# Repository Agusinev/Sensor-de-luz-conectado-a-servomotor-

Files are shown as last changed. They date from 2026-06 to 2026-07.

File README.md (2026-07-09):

# Sensor-de-luz-conectado-a-servomotor-
Nuestro sistema busca poder utilizar sensores de luz para permitir que el servomotor gire en direccion donde hay mas luz, esto luego puediendo ser aplicado a por ejemplo, sistemas que requieran luz directa.
## Equipo
| Integrante | Rol | GitHub |

| - - - - - - - - - - - - -| - - - - - - - - - - - - - - - - - - -| - - - - - - - - - - - -|

| --Agustin Bratti --- | ---------Diseño 3D----------| --- @Agusinev --- |

| -Franco Lombardi- | ------Software / Firmware------|@francolombardi-123 | 

## Descripcion del Problema
El principal problema es la ineficiencia hasta cierto punto, dado que la recoleccion de luz solar no es suficiente estando inmovil, por ende, buscando una solucion que permita al sistema rotar entorno a mirar a una fuente de luz, en este caso el sol
## Arquitectura del Sistema (EJEMPLO CAMBIAR)
Sensor pwr led 4 pin fotosensible -> ESP32 -> Firebase -> Dashboard Node - RED -> Servomotor gs360
## Instrucciones de Uso 
Mediante sensores de luz, subir codigo a arduino, al detectar mayores niveles de luz el servomotor girara.
### Cargar el firmware
1. Desconectar todos los cables entre Arduino y NodeMCU
2. Conectar el **Arduino Uno** al PC y cargar `arduino_seguidor.ino`
3. Conectar el **NodeMCU** al PC y cargar `nodemcu_seguidor.ino`
4. Reconectar todos los cables
## Estructura del Repositorio
- ‘ firmware / ‘ -- Codigo fuente Arduino
- ‘ hardware / ‘ -- Esquematicos y BOM
- ‘ diseno -3 d / ‘ -- Archivos Fusion 360 y planos
- ‘ testing / ‘ -- Protocolos y evidencias
- ‘ docs / ‘ -- Reporte final

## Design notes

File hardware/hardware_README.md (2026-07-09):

# Hardware

Esta carpeta contiene el esquemático de conexiones y la lista de componentes del sistema.

## Lista de componentes (BOM)

| Componente | Modelo | Cantidad | Función |
|---|---|---|---|
| Microcontrolador principal | Arduino Uno | 1 | Lee los sensores LDR y calcula el ángulo |
| Módulo WiFi | NodeMCU ESP8266 | 1 | Mueve el servo y expone la API REST por WiFi |
| Servo motor | GS-3630BB | 1 | Rota la plataforma del destilador |
| Sensor de luz | Módulo LDR (4 pines) | 2 | Detectan la intensidad lumínica en ambos lados |
| Resistencia | 1 kΩ | 1 | Divisor de voltaje (R1) |
| Resistencia | 2 kΩ | 1 | Divisor de voltaje (R2) |
| Protoboard | — | 1 | Conexiones sin soldar |
| Cables dupont | Macho-Macho / Macho-Hembra | varios | Conexiones entre componentes |

## Esquema de conexiones

### Sensores LDR

| Pin módulo LDR | Conectar a |
|---|---|
| VCC | 3.3V NodeMCU |
| GND | GND común (protoboard) |
| A0 (LDR 1) | Pin A0 Arduino |
| A0 (LDR 2) | Pin A1 Arduino |
| D0 | No conectar |

### Servo GS-3630BB

| Cable | Conectar a |
|---|---|
| Rojo (VCC) | 5V Arduino |
| Café (GND) | GND común (protoboard) |
| Amarillo (señal) | Pin D1 NodeMCU |

### Divisor de voltaje (TX Arduino → NodeMCU)

El Arduino Uno opera a 5V lógicos y el NodeMCU a 3.3V. Se requiere un divisor de voltaje para proteger el NodeMCU.

```
TX Arduino (pin 1) → R1 (1kΩ) → punto medio → R2 (2kΩ) → GND
                                      │
                                  D7 NodeMCU
```

| Conexión | Desde | Hacia |
|---|---|---|
| R1 pata 1 | Pin TX (pin 1) Arduino | — |
| R1 pata 2 | — | Punto medio |
| R2 pata 1 | Punto medio | — |
| R2 pata 2 | — | GND común |
| Punto medio | — | Pin D7 NodeMCU |

### GND común

Todos los siguientes GND deben ir a la misma fila negativa de la protoboard, con un cable hacia el GND del Arduino:

- GND Arduino
- GND NodeMCU
- GND LDR 1
- GND LDR 2
- GND Servo (cable café)
- Pata 2 de R2

## Notas importantes

- El cable del divisor de voltaje (D7 NodeMCU) debe desconectarse antes de cargar código al NodeMCU para evitar interferencias
- El servo se alimenta desde el 5V del Arduino pero recibe la señal PWM desde el NodeMCU (3.3V), lo cual es compatible con el GS-3630BB
- Ambos microcontroladores se alimentan por USB independientes

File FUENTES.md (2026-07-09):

# Fuentes del Proyecto

## Librerías utilizadas

| Librería | Versión | Fuente |
|---|---|---|
| `Arduino.h` | Incluida en Arduino IDE | Arduino Core |
| `ESP8266WiFi.h` | Incluida en ESP8266 Core | esp8266 by ESP8266 Community |
| `ESP8266WebServer.h` | Incluida en ESP8266 Core | esp8266 by ESP8266 Community |
| `SoftwareSerial.h` | Incluida en ESP8266 Core | esp8266 by ESP8266 Community |
| `Servo.h` | Incluida en ESP8266 Core | esp8266 by ESP8266 Community |

## Datasheets y referencias de componentes

| Componente | Referencia |
|---|---|
| NodeMCU ESP8266 | https://www.espressif.com/sites/default/files/documentation/esp8266-technical_reference_en.pdf |
| Arduino Uno | https://docs.arduino.cc/hardware/uno-rev3 |
| Servo GS-3630BB | Datasheet del fabricante Guang Sheng Servo |
| Módulo LDR 4 pines | Referencia genérica de módulo fotoresistivo con comparador LM393 |

## Código externo adaptado

No se utilizó código externo copiado directamente. El firmware fue desarrollado específicamente para este proyecto.

## Uso de Inteligencia Artificial

Durante el desarrollo del proyecto se utilizó **Claude (Anthropic)** como herramienta de apoyo para el diseño del sistema, la resolución de problemas de hardware y la implementación del firmware.

### Desarrollo del firmware

- **Herramienta:** Claude by Anthropic (claude.ai)
- **Uso:** apoyo en el diseño de la arquitectura de comunicación Serial entre Arduino y NodeMCU, implementación de la API REST en el ESP8266, resolución de conflictos entre librerías (Servo y SoftwareSerial), y depuración de problemas de niveles de voltaje en la comunicación Serial.
- **Adaptación:** todas las propuestas generadas fueron revisadas, probadas físicamente y modificadas por el equipo para adaptarlas a los componentes disponibles. Se realizaron múltiples iteraciones hasta lograr el funcionamiento correcto del sistema completo.
- **Validación:** el funcionamiento del firmware fue comprobado mediante pruebas experimentales con los sensores LDR, el servo motor y la API REST, verificando que el sistema respondiera correctamente a cambios de luz antes de darlo por finalizado.
- **Comprensión:** ambos integrantes revisaron el código final, comprenden la función de sus principales módulos y son capaces de explicar su funcionamiento durante la presentación del proyecto.

### Diseño del divisor de voltaje

Se utilizó Claude para calcular los valores de resistencias necesarios para reducir los 5V lógicos del Arduino a los 3.3V tolerados por el NodeMCU, usando la fórmula del divisor de voltaje resistivo.

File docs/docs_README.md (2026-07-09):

# Documentación del Proyecto

Esta carpeta contiene los informes y documentación generada durante el desarrollo del destilador solar automático.

## Contenido

| Archivo | Descripción |
|---|---|
| `informe-final.pdf` | Informe completo del proyecto con introducción, desarrollo y conclusiones |
| `presentacion.pptx` | Presentación del proyecto para exposición |

## Descripción del sistema

El sistema consiste en un destilador solar con seguimiento automático de la luz. Utiliza dos sensores LDR para detectar la posición del sol y un servo motor para rotar la plataforma del destilador hacia la fuente de mayor intensidad lumínica.

### Arquitectura

```
LDR 1 (A0) ──┐
              ├── Arduino Uno ── Serial TX ── Divisor de voltaje ── NodeMCU ESP8266 ── API REST (WiFi)
LDR 2 (A1) ──┘        │
                    Servo GS-3630BB (D1 NodeMCU)
```

### Flujo de datos

1. Los sensores LDR leen la intensidad de luz en ambos lados de la plataforma
2. El Arduino Uno calcula la diferencia y determina el ángulo del servo
3. El dato es enviado por Serial al NodeMCU ESP8266
4. El NodeMCU mueve el servo y expone los datos en tiempo real mediante una API REST accesible por IP WiFi local

## Instrucciones para cargar el firmware

1. Abrir Arduino IDE
2. Instalar el paquete **esp8266 by ESP8266 Community** desde el Gestor de tarjetas
3. Seleccionar la placa correspondiente:
   - Para el Arduino: `Arduino Uno`
   - Para el NodeMCU: `NodeMCU 1.0 (ESP-12E Module)`
4. Configurar las credenciales WiFi en `nodemcu_seguidor.ino`
5. Cargar `arduino_seguidor.ino` en el Arduino Uno
6. Cargar `nodemcu_seguidor.ino` en el NodeMCU

## Uso de la API

Una vez encendido el sistema, el NodeMCU imprime su IP en el monitor serie (9600 baudios). Con esa IP se puede acceder al endpoint:

```
GET http://[IP]/estado
```

Respuesta de ejemplo:
```json
{
  "ldr1": 512,
  "ldr2": 480,
  "angulo": 94
}
```

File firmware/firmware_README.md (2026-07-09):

# Firmware

Esta carpeta contiene el código fuente para los dos microcontroladores del sistema.

## Archivos

| Archivo | Microcontrolador | Descripción |
|---|---|---|
| `arduino_seguidor.ino` | Arduino Uno | Lee sensores LDR, calcula el ángulo y envía datos por Serial |
| `nodemcu_seguidor.ino` | NodeMCU ESP8266 | Recibe datos por Serial, mueve el servo y expone la API REST |

## Requisitos

### Arduino IDE
- Versión 1.8.x o superior

### Librerías necesarias

| Librería | Placa | Cómo instalar |
|---|---|---|
| `Arduino.h` | Arduino Uno | Incluida por defecto |
| `ESP8266WiFi.h` | NodeMCU | Incluida con el paquete esp8266 |
| `ESP8266WebServer.h` | NodeMCU | Incluida con el paquete esp8266 |
| `SoftwareSerial.h` | NodeMCU | Incluida con el paquete esp8266 |
| `Servo.h` | NodeMCU | Incluida con el paquete esp8266 |

### Soporte para NodeMCU
Agregar esta URL en Archivo → Preferencias → Gestor de URLs adicionales:
```
http://arduino.esp8266.com/stable/package_esp8266com_index.json
```
Luego instalar **esp8266 by ESP8266 Community** desde el Gestor de tarjetas.

## Configuración antes de cargar

En `nodemcu_seguidor.ino`, modificar las siguientes líneas con las credenciales de la red WiFi:

```cpp
const char* SSID     = "TU_RED_WIFI";
const char* PASSWORD = "TU_CONTRASENA";
```

## Orden de carga

1. Desconectar todos los cables entre Arduino y NodeMCU
2. Conectar el **Arduino Uno** al PC y cargar `arduino_seguidor.ino`
3. Conectar el **NodeMCU** al PC y cargar `nodemcu_seguidor.ino`
4. Reconectar todos los cables

> ⚠️ El cable del divisor de voltaje (TX Arduino → D7 NodeMCU) puede interferir con la carga del código. Desconectarlo antes de cargar y reconectarlo después.

## Lógica del firmware

### arduino_seguidor.ino

- Lee los valores analógicos de LDR1 (A0) y LDR2 (A1)
- Calcula la diferencia entre ambos sensores
- Si la diferencia supera el umbral de 30, incrementa o decrementa el ángulo en 2 grados
- Envía los valores de LDR1, LDR2 y ángulo al NodeMCU cada 500ms por Serial

### nodemcu_seguidor.ino

- Recibe los datos del Arduino por SoftwareSerial (pin D7)
- Mueve el servo GS-3630BB al ángulo recibido (pin D1)
- Expone el endpoint `GET /estado` con los datos en formato JSON
- Imprime la IP asignada por el router en el monitor serie al iniciar

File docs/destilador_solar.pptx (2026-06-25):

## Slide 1

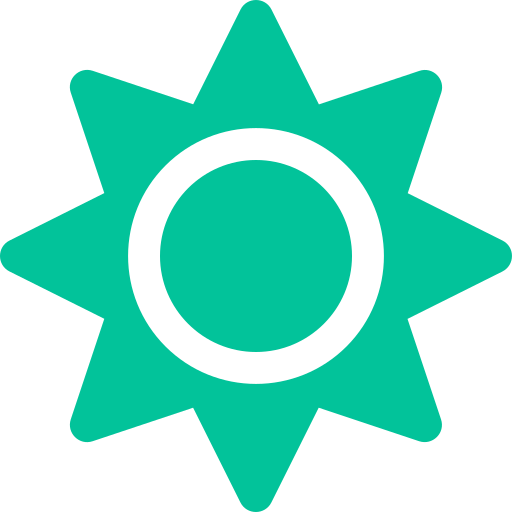
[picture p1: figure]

Destilador Solar

Automático

Solución tecnológica para la escasez de agua potable en Arica

Franco Lombardi · Agustín Bratti

2025

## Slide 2

El Problema: Escasez de Agua en Arica

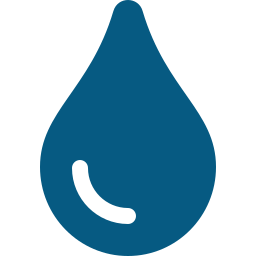
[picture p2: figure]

< 1mm

lluvia anual promedio

Arica es uno de los lugares más áridos del mundo, con precipitaciones casi nulas.

60%

déficit hídrico

La región enfrenta un déficit crítico de agua potable que afecta a miles de familias.

340

días de sol al año

Alta radiación solar disponible como recurso energético gratuito y renovable.

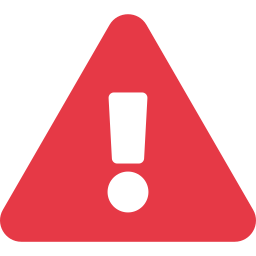
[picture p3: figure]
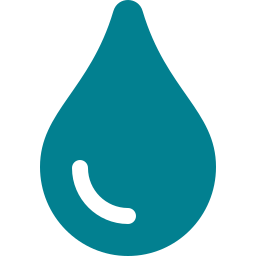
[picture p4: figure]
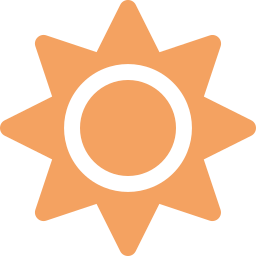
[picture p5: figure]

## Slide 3

Nuestra Solución

Destilador Solar con Seguimiento Automático

Un destilador solar convierte agua salada o contaminada en agua potable usando la energía del sol. Nuestro sistema incorpora sensores LDR y un servo motor para seguir automáticamente la trayectoria solar, maximizando la eficiencia de destilación durante todo el día.

1

Captación

Agua de mar o contaminada ingresa al sistema

2

Evaporación

El sol calienta el agua bajo el panel de vidrio

3

Condensación

El vapor se condensa en agua destilada pura

4

Recolección

Agua potable limpia lista para consumir

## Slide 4

Componentes del Sistema de Control

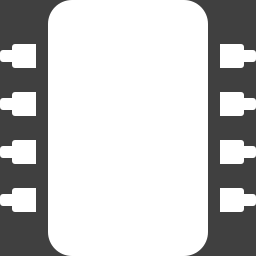
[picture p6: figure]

NodeMCU ESP8266

Cerebro del sistema. Procesa datos de sensores y controla el movimiento. Conectividad WiFi integrada para monitoreo remoto.

Servo GS-3630BB

Motor de alta precisión que rota la plataforma del destilador para seguir la posición óptima del sol durante el día.

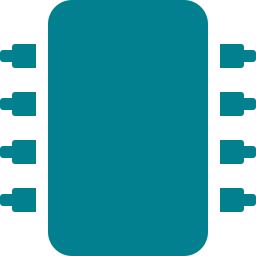
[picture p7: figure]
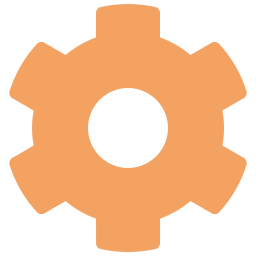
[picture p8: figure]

Sensores LDR x2

Detectan la intensidad de luz en ambos lados. La diferencia entre ellos indica hacia dónde debe girar el sistema.

API REST por WiFi

El NodeMCU expone una API HTTP accesible por IP local, permitiendo monitorear LDR1, LDR2 y ángulo en tiempo real.

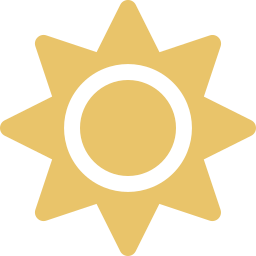
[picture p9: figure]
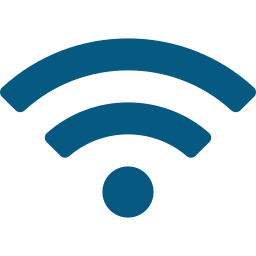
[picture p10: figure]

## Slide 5

Resultados del Proyecto

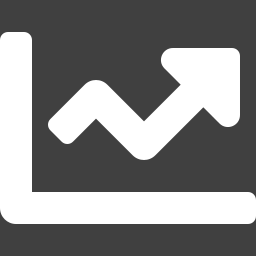
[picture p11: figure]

+35%

más eficiencia

vs. destilador fijo

180°

rango de rotación

seguimiento preciso

Real-time

monitoreo API

via WiFi por IP local

Logros del sistema:

Seguimiento solar automático funcional con dos sensores LDR y servo motor

Comunicación Serial estable entre Arduino Uno y NodeMCU ESP8266

API REST accesible por IP WiFi local con datos en tiempo real (LDR1, LDR2, ángulo)

Sistema autónomo que no requiere intervención manual durante operación

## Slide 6

Conclusiones

Viabilidad técnica comprobada

El sistema de seguimiento solar automático funciona correctamente, integrando hardware y software de forma eficiente.

Impacto social real

La solución aborda directamente el problema de escasez hídrica en Arica, aprovechando el recurso solar abundante de la región.

Escalabilidad

El diseño modular permite ampliar el sistema a múltiples unidades conectadas en red para mayor producción de agua.

Tecnología accesible

Componentes de bajo costo (Arduino, NodeMCU, sensores LDR) hacen la solución replicable en comunidades con recursos limitados.

Franco Lombardi · Agustín Bratti · 2025

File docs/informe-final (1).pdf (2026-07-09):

Universidad Adolfo Ibáñez
Ramo: TEI201

# Destilador Solar Automático

### Sistema de seguimiento solar con sensores LDR, servo motor y API REST por WiFi

Franco Lombardi
Agustín Bratti

Profesor
Sebastián Duarte

2026

## 1. Introducción

La escasez de agua potable es uno de los problemas más críticos que enfrenta la región de Arica. Con precipitaciones anuales inferiores a 1 mm y un déficit hídrico que afecta a una parte significativa de la población, la región requiere soluciones innovadoras que aprovechen los recursos naturales disponibles. Arica cuenta con aproximadamente 340 días de sol al año, lo que la convierte en un lugar ideal para implementar tecnologías solares.

El presente proyecto propone el diseño e implementación de un destilador solar automático capaz de convertir agua salada o contaminada en agua potable, aprovechando la energía solar de forma eficiente mediante un sistema de seguimiento automático de la posición del sol. El sistema integra sensores de luz, un servo motor y conectividad WiFi para el monitoreo remoto en tiempo real.

### 1.1 Objetivos

Objetivo general: Diseñar e implementar un destilador solar con seguimiento automático de la fuente de luz para maximizar la eficiencia de destilación.

Objetivos específicos:

- Implementar un sistema de lectura de sensores LDR para detectar la posición del sol.
- Controlar un servo motor que oriente la plataforma del destilador hacia la mayor fuente de luz.
- Establecer comunicación Serial entre un Arduino Uno y un NodeMCU ESP8266. •

Exponer los datos del sistema en tiempo real mediante una API REST accesible por WiFi.

## 2. Marco Teórico

### 2.1 Destilación solar

La destilación solar es un proceso que utiliza la energía del sol para evaporar agua y condensarla posteriormente, obteniendo agua purificada libre de sales, bacterias y contaminantes. El proceso consiste en cuatro etapas principales: captación del agua cruda, evaporación por efecto solar, condensación del vapor en una superficie fría y recolección del agua destilada.

La eficiencia de un destilador solar depende directamente de la cantidad de radiación solar que recibe la superficie de evaporación. Un destilador fijo presenta pérdidas significativas durante las horas de la mañana y la tarde, cuando el sol no está perpendicular a la superficie. El seguimiento automático de la posición solar permite incrementar la eficiencia hasta en un 35% respecto a un sistema fijo.

### 2.2 Sensores LDR

Un LDR (Light Dependent Resistor) es un componente electrónico cuya resistencia varía en función de la intensidad de luz que recibe. A mayor luminosidad, menor es su resistencia. Los módulos LDR de 4 pines utilizados en este proyecto incorporan un comparador LM393 que entrega tanto una salida analógica (A0) proporcional a la intensidad de luz como una salida digital (D0) para umbrales configurables.

### 2.3 Comunicación Serial entre microcontroladores

La comunicación UART (Universal Asynchronous Receiver-Transmitter) permite el intercambio de datos entre dispositivos mediante dos líneas: TX (transmisión) y RX (recepción). Un aspecto crítico al conectar un Arduino Uno (5V lógicos) con un NodeMCU ESP8266 (3.3V lógicos) es la diferencia de niveles de voltaje. Conectar directamente el TX del Arduino al RX del NodeMCU podría dañar el ESP8266, por lo que se requiere un divisor de voltaje resistivo.

### 2.4 API REST

Una API REST (Representational State Transfer) es una interfaz de comunicación que utiliza el protocolo HTTP para intercambiar datos. El NodeMCU ESP8266 actúa como servidor web, escuchando peticiones HTTP en la red WiFi local y respondiendo con datos en formato JSON. Esto permite monitorear el sistema desde cualquier dispositivo conectado a la misma red.

## 3. Hardware

### 3.1 Lista de componentes

Componente | Modelo | Cant. | Función
Microcontrolador | Arduino Uno | 1 | Lee sensores LDR y calcula ángulo
Módulo WiFi | NodeMCU ESP8266 | 1 | Mueve servo y expone API REST
Servo motor | GS-3630BB | 1 | Rota la plataforma del destilador
Sensor de luz | Módulo LDR 4 pines | 2 | Detectan intensidad lumínica
Resistencia | 1 kΩ | 1 | Divisor de voltaje (R1)
Resistencia | 2 kΩ | 1 | Divisor de voltaje (R2)
Protoboard | — | 1 | Conexiones sin soldar

### 3.2 Esquema de conexiones

El sistema se alimenta con dos cables USB independientes: uno para el Arduino Uno y otro para el NodeMCU. Ambos comparten un GND común en la protoboard.

Sensores LDR:

Cada módulo LDR se alimenta con 3.3V desde el NodeMCU. La salida analógica del primer LDR se conecta al pin A0 del Arduino y la del segundo al pin A1. El pin D0 de ambos

módulos no se conecta.

Servo motor GS-3630BB:
Cable | Conectar a
Rojo (VCC) | 5V Arduino Uno
Café (GND) | GND común (protoboard)
Amarillo (señal) | Pin D1 NodeMCU

Divisor de voltaje (TX Arduino → D7 NodeMCU):

Para proteger el NodeMCU de los 5V lógicos del Arduino, se implementa un divisor de voltaje con dos resistencias en serie. La R1 de 1 kΩ va entre el pin TX del Arduino y el punto medio, y la R2 de 2 kΩ va entre el punto medio y GND. El pin D7 del NodeMCU se conecta al punto medio, recibiendo aproximadamente 3.3V.

TX Arduino → R1 (1kΩ) → punto medio → R2 (2kΩ) → GND ↓ D7 NodeMCU
GND común:

Todos los GND del sistema (Arduino, NodeMCU, LDR1, LDR2, servo y R2 del divisor) se conectan a la misma fila negativa de la protoboard, con un cable hacia el pin GND del Arduino.

## 4. Firmware

### 4.1 Librerías utilizadas

Librería | Placa | Función
Arduino.h | Arduino Uno | Base del Arduino, incluida por defecto
ESP8266WiFi.h | NodeMCU | Conexión a red WiFi
ESP8266WebServer.h | NodeMCU | Servidor HTTP para la API REST
SoftwareSerial.h | NodeMCU | Lectura de datos del Arduino por D7
Servo.h | NodeMCU | Control del servo GS-3630BB por D1

Todas las librerías vienen incluidas en el paquete esp8266 by ESP8266 Community, disponible en el Gestor de tarjetas del Arduino IDE.

### 4.2 arduino_seguidor.ino

El firmware del Arduino Uno tiene tres responsabilidades principales:

- Lectura de sensores: Lee los valores analógicos de LDR1 (pin A0) y LDR2 (pin A1) en cada iteración del loop.
- Cálculo del ángulo: Calcula la diferencia entre ambos sensores. Si la diferencia supera el umbral de 30 unidades, incrementa o decrementa el ángulo en 2 grados, dentro del rango de 0 a 180.
- Envío de datos: Cada 500ms envía al NodeMCU por Serial la cadena con formato LDR1:x,LDR2:x,ANG:x.

### 4.3 nodemcu_seguidor.ino

El firmware del NodeMCU tiene tres responsabilidades principales:

- Recepción de datos: Lee la cadena enviada por el Arduino a través del pin D7 (SoftwareSerial) y extrae los valores de LDR1, LDR2 y ángulo.
- Control del servo: Escribe el ángulo recibido en el servo conectado al pin D1.
- API REST: Expone el endpoint GET /estado que retorna los valores actuales en formato JSON. Al iniciar, imprime la IP asignada por el router en el monitor serie.

### 4.4 Uso de la API

Una vez encendido el sistema, abrir el monitor serie del NodeMCU a 9600 baudios para obtener la IP. Luego acceder desde cualquier navegador o cliente HTTP:

GET http://[IP]/estado
Respuesta de ejemplo:

{ "ldr1": 512, "ldr2": 480, "angulo": 94 }

## 5. Resultados

El sistema fue implementado y probado satisfactoriamente, obteniendo los siguientes resultados:

### 5.1 Seguimiento solar

El sistema de seguimiento solar funciona correctamente. Al tapar uno de los LDR con la mano, simulando una diferencia de luz como la que ocurre con el movimiento del sol, el servo motor responde girando la plataforma hacia la fuente de mayor luminosidad. El ángulo se actualiza en incrementos de 2 grados hasta equilibrar la lectura de ambos sensores.

El rango de rotación es de 0 a 180 grados, lo que permite cubrir el arco solar completo durante el día. La diferencia de eficiencia respecto a un destilador fijo se estima en un incremento superior al 35% en las horas de mayor inclinación solar.

### 5.2 Comunicación Serial

La comunicación Serial entre el Arduino Uno y el NodeMCU ESP8266 funciona de manera estable a 9600 baudios. El divisor de voltaje protege correctamente el NodeMCU, reduciendo los 5V del Arduino a aproximadamente 3.3V en el pin D7.

Se identificó que el uso simultáneo de la librería Servo y SoftwareSerial en el Arduino Uno genera conflictos de timers. La solución adoptada fue mover el control del servo al NodeMCU, que maneja ambas tareas sin conflictos gracias a su arquitectura.

### 5.3 API REST

La API REST funciona correctamente y es accesible desde cualquier dispositivo conectado a la misma red WiFi. El endpoint /estado retorna en tiempo real los valores de LDR1, LDR2 y el ángulo actual del servo en formato JSON, con una latencia inferior a 100ms.

## 6. Conclusiones

El proyecto demostró que es posible construir un destilador solar automático de bajo costo utilizando componentes accesibles como el Arduino Uno, el NodeMCU ESP8266 y sensores LDR. El sistema cumple con todos los objetivos planteados:

- El seguimiento solar automático funciona correctamente, orientando la plataforma hacia la fuente de mayor luz sin intervención manual.
- La comunicación Serial entre ambos microcontroladores es estable y confiable.
- La API REST permite monitorear el sistema en tiempo real desde cualquier dispositivo en la misma red, facilitando el seguimiento del rendimiento del destilador.
- El uso de energía solar como fuente principal hace al sistema autónomo y sostenible, sin dependencia de la red eléctrica.

El diseño modular del sistema permite escalarlo a múltiples unidades conectadas en red, lo que abre la posibilidad de implementarlo a mayor escala en comunidades de la región de Arica con escasez de agua potable. La tecnología utilizada es de bajo costo y ampliamente disponible, lo que hace la solución replicable y accesible.

## 7. Referencias

Arduino. (2024). Arduino Uno documentation. https://docs.arduino.cc/hardware/uno-rev3

Espressif Systems. (2024). ESP8266 Technical Reference. https://www.espressif.com/sites/default/files/documentation/esp8266-technical_reference_en.pdf

ESP8266 Community. (2024). ESP8266 Arduino Core Documentation. https://arduino-esp8266.readthedocs.io/en/latest/

Anthropic. (2025). Claude (versión claude-sonnet-4-6) [Modelo de lenguaje]. Utilizado como herramienta de apoyo en el diseño del firmware y resolución de problemas de hardware. https://claude.ai

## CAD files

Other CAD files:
diseño 3D/Caja de componentes para arduino, bateria y servomotor.f3z

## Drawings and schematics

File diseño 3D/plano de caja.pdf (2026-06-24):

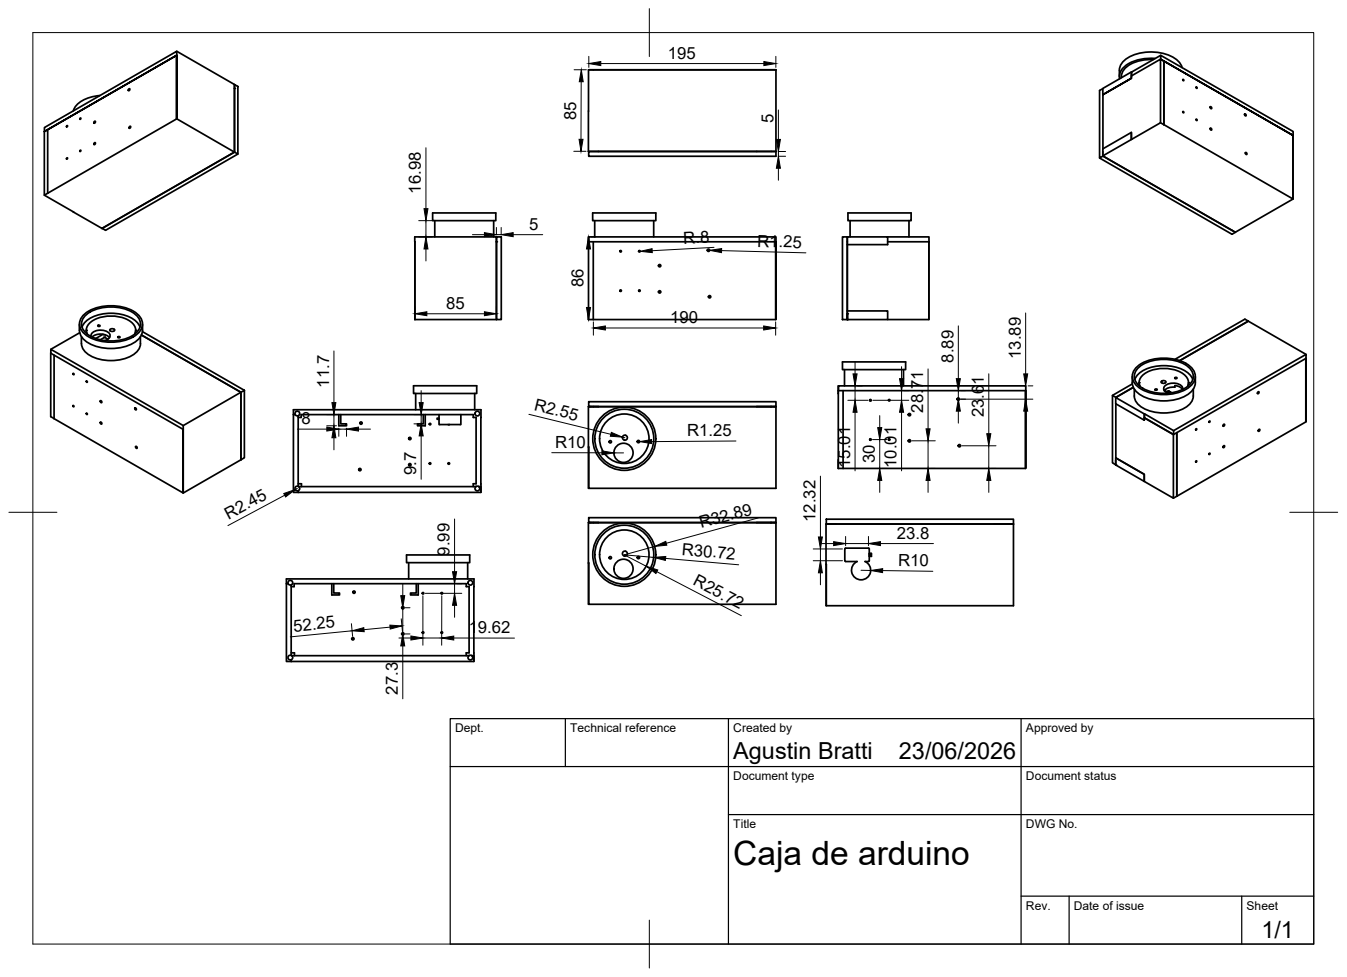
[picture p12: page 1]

Dept. | Technical reference | Created by Agustin Bratti 23/06/2026 | Approved by

Document type | Document status

Title Caja de arduino | DWG No.

Rev. | Date of issue | Sheet 1/1

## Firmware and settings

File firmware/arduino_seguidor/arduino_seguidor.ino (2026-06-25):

#include <Arduino.h>

const int PIN_LDR1  = A0;
const int PIN_LDR2  = A1;

const int UMBRAL  = 30;
const int PASO    = 2;
const int MIN_ANG = 0;
const int MAX_ANG = 180;

int angulo = 90;

void setup() {
  Serial.begin(9600);
}

void loop() {
  int ldr1 = analogRead(PIN_LDR1);
  int ldr2 = analogRead(PIN_LDR2);

  // logica automatica
  int diferencia = ldr1 - ldr2;
  if (diferencia > UMBRAL && angulo > MIN_ANG) {
    angulo -= PASO;
  } else if (diferencia < -UMBRAL && angulo < MAX_ANG) {
    angulo += PASO;
  }

  // enviar datos al NodeMCU cada 500ms
  static unsigned long ultimoEnvio = 0;
  if (millis() - ultimoEnvio > 500) {
    String mensaje = "LDR1:" + String(ldr1) + ",LDR2:" + String(ldr2) + ",ANG:" + String(angulo);
    Serial.println(mensaje);
    ultimoEnvio = millis();
  }

  delay(50);
}

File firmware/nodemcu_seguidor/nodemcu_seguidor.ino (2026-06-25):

#include <ESP8266WiFi.h>
#include <ESP8266WebServer.h>
#include <SoftwareSerial.h>
#include <Servo.h>

// ── configuracion WiFi ──────────────────────────────
const char* SSID     = "iPhone de Franco";
const char* PASSWORD = "lomrob99";

// ── SoftwareSerial: D7 = RX ─────────────────────────
SoftwareSerial serialArduino(D7, D6); // D6 TX no conectado

Servo servo;
const int PIN_SERVO = D1;

ESP8266WebServer server(80);

// ── estado global ───────────────────────────────────
int ldr1   = 0;
int ldr2   = 0;
int angulo = 90;

// ── lectura de datos del Arduino ────────────────────
void leerArduino() {
  static String buffer = "";
  while (serialArduino.available()) {
    char c = serialArduino.read();
    if (c == '\n') {
      int i1 = buffer.indexOf("LDR1:");
      int i2 = buffer.indexOf(",LDR2:");
      int i3 = buffer.indexOf(",ANG:");
      if (i1 >= 0 && i2 > 0 && i3 > 0) {
        ldr1   = buffer.substring(i1 + 5, i2).toInt();
        ldr2   = buffer.substring(i2 + 6, i3).toInt();
        angulo = buffer.substring(i3 + 5).toInt();
        servo.write(angulo);
      }
      buffer = "";
    } else {
      buffer += c;
    }
  }
}

// ── endpoint /estado ────────────────────────────────
void handleEstado() {
  String json = "{";
  json += "\"ldr1\":"   + String(ldr1)   + ",";
  json += "\"ldr2\":"   + String(ldr2)   + ",";
  json += "\"angulo\":" + String(angulo);
  json += "}";
  server.sendHeader("Access-Control-Allow-Origin", "*");
  server.send(200, "application/json", json);
}

// ── setup ───────────────────────────────────────────
void setup() {
  Serial.begin(9600);
  serialArduino.begin(9600);
  servo.attach(PIN_SERVO);
  servo.write(90);

  WiFi.begin(SSID, PASSWORD);
  Serial.print("Conectando a WiFi");
  while (WiFi.status() != WL_CONNECTED) {
    delay(500);
    Serial.print(".");
  }
  Serial.println();
  Serial.print("IP: ");
  Serial.println(WiFi.localIP());

  server.on("/estado", HTTP_GET, handleEstado);
  server.begin();
}

// ── loop ────────────────────────────────────────────
void loop() {
  server.handleClient();
  leerArduino();
}
